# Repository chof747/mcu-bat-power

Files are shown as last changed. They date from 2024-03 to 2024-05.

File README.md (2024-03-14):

# mcu-bat-power

Battery power board for 5v compatible MCU boards featuring a LiFePo4 Holder

## Idea

This project is a battery supplied power circuitry to supply microcontroller projects with 5V battery power + the ability to charge and protect a LiFePo4 battery. In addition breakout for the USB data lines, voltage and current 
measurement as well as the sensing pins of the charging circuit are added so that a proper power management from
the microcontroller on an attached board is possible.

The concept of the board is to act as an add on board for a microcontroller board in a way that it can work for
several battery powered projects.

The idea is based on a Great Scott's video and materials of a [DIY LiPo Charge/Protect/5V Boost Circuit](https://www.youtube.com/watch?v=Fj0XuYiE7HU&t=618s)

## Components
This board includes a:

- LiFePo4 charging IC (CN3058E)
- Battery protection circuitry (HY2112 + FS8205)
- 5V Boost converter (MT3608 + passive components)
- A Micro USB socket to charge it conviniently from micro USB
- A power measurement circuit (INA219AxD with a 100mOhm sensing resistor)
- Leds for Power, Charging and Done
- A Power Switch
- Three connectors for other boards:
    - 5V/GND
    - Signals and Measuring:
        - Chargin and Done signal from the charging IC
        - I2C Bus for INA219A
        - VREF and GND connections to bring in the voltage level and power from a specific microcontroller
    - D+/D- from the USB Line

## Schematic & Board Layout

Schematic

Board Layout

## Revision History:

- **v1.0**: Initial version (Produced: 13.03.2024)<br/>
  This initial version includes a view additional features to enable better testing:
    - Test pads for all important voltage levels, signals and gnd
    - Additional pads to pass 5V power from a power supply
    - a bit more space (battery and circiutry are on the same side of the board)

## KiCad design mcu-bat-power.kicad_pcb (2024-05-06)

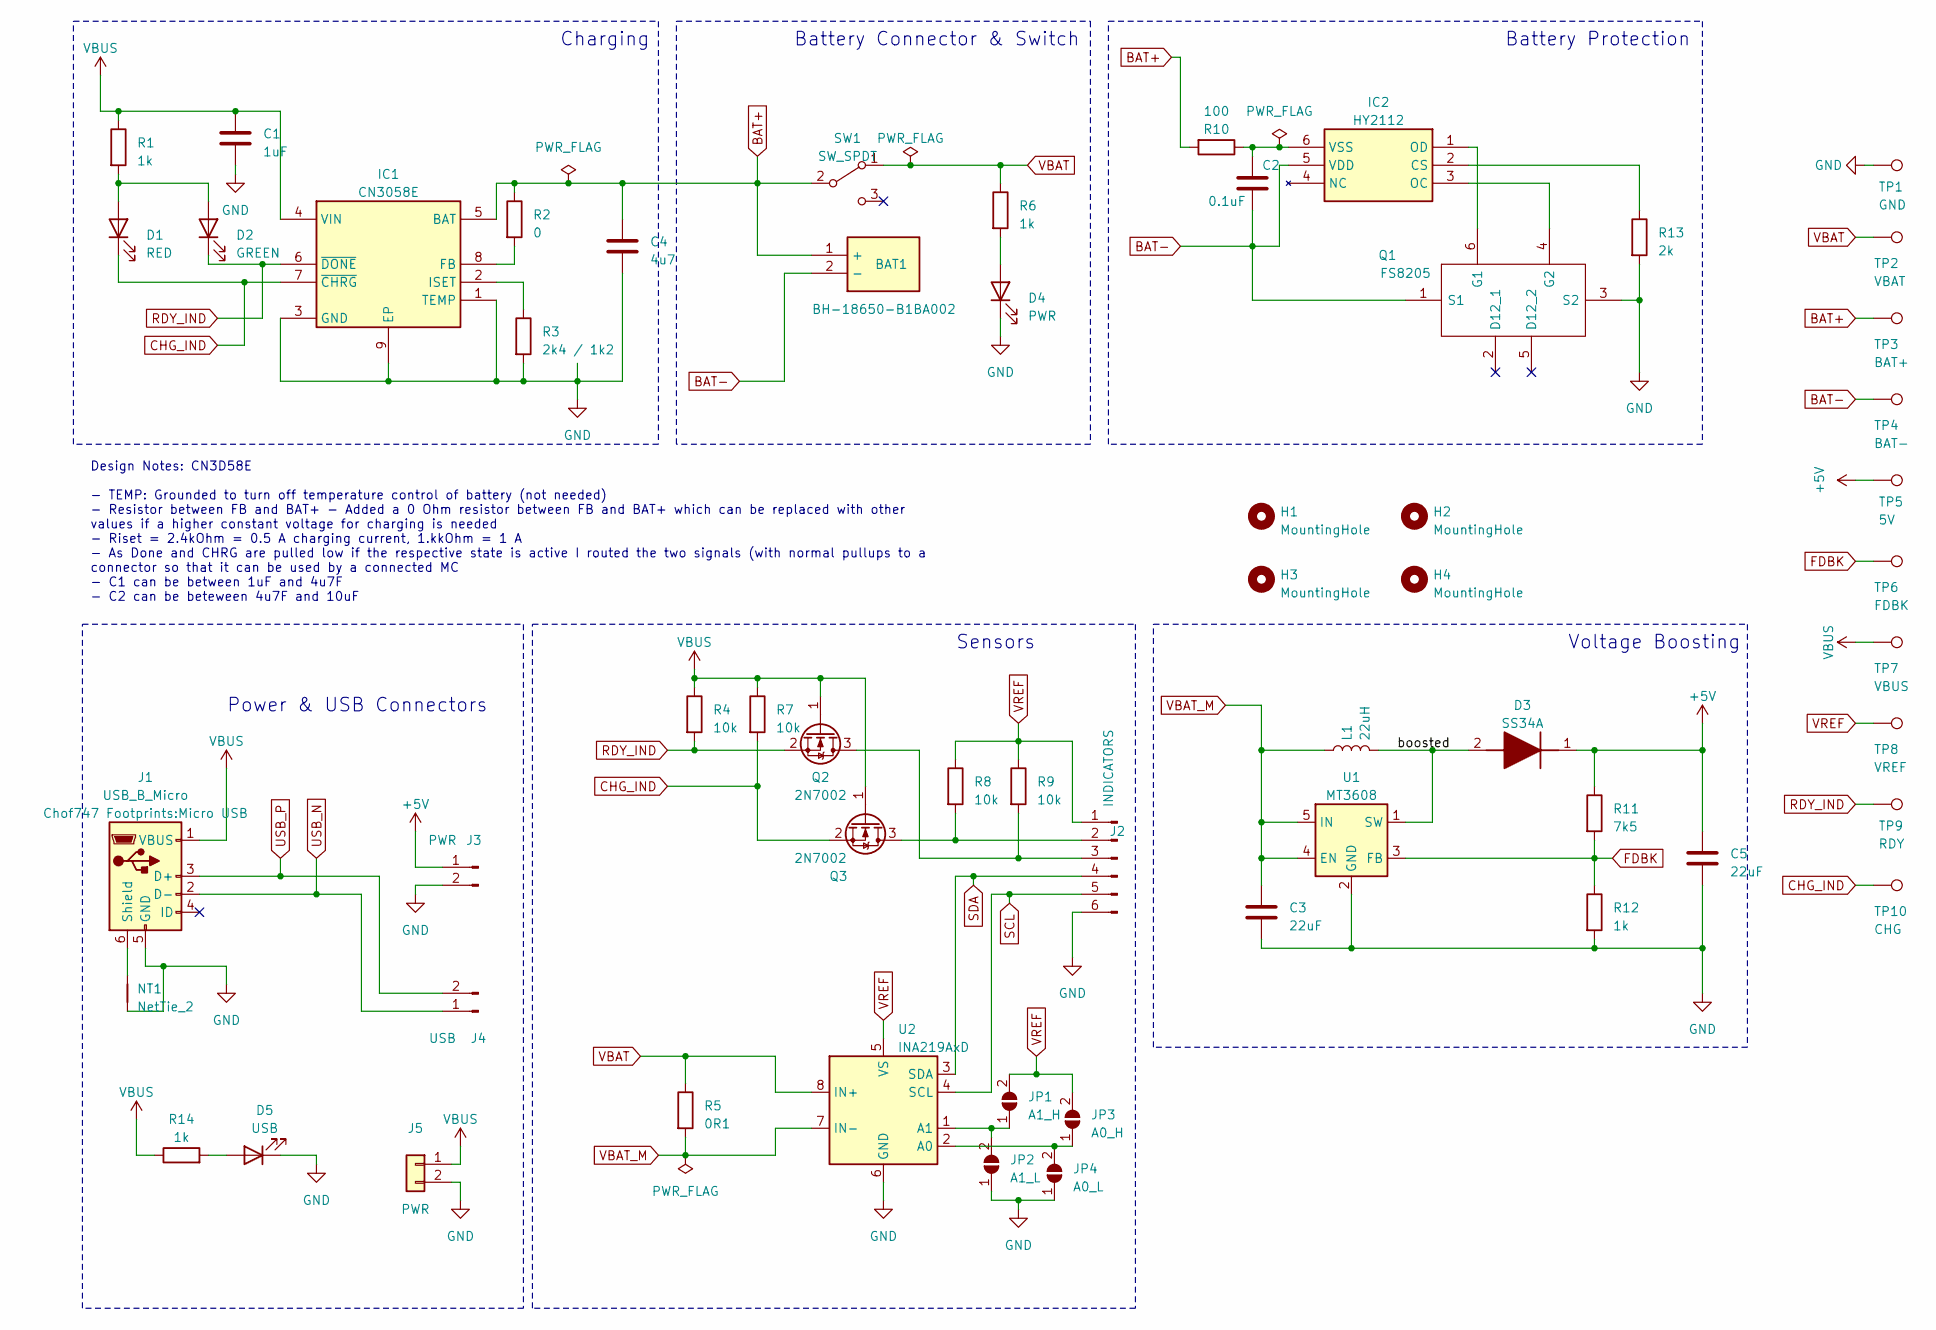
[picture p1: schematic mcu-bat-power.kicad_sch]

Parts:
BAT1: BH-18650-B1BA002; BH18650B1BA002; Manufacturer_Part_Number BH-18650-B1BA002
C1: 1uF; C_0603_1608Metric_Pad1.08x0.95mm_HandSolder
C2: 0.1uF; C_0603_1608Metric_Pad1.08x0.95mm_HandSolder
C3, C5: 22uF; C_1206_3216Metric_Pad1.33x1.80mm_HandSolder
C4: 4u7; C_0603_1608Metric_Pad1.08x0.95mm_HandSolder
D1: RED; LED_0603_1608Metric_Pad1.05x0.95mm_HandSolder
D2: GREEN; LED_0603_1608Metric_Pad1.05x0.95mm_HandSolder
D3: SS34A; DIOM5026X262N; Manufacturer_Part_Number SS34A
D4: PWR; LED_0603_1608Metric_Pad1.05x0.95mm_HandSolder
D5: USB; LED_0603_1608Metric_Pad1.05x0.95mm_HandSolder
H1, H2, H3, H4: MountingHole; MountingHole_3.2mm_M3-smallBorder
IC1: CN3058E; SOIC127P600X175-9N; Manufacturer_Part_Number CN3058E
IC2: HY2112; SOT95P280X145-6N; Manufacturer_Part_Number HY2112
J1: USB_B_Micro; Micro USB
J2: INDICATORS; PinHeader_1x06_P2.54mm_Horizontal
J3: PWR; PinHeader_1x02_P2.54mm_Horizontal
J4: USB; PinHeader_1x02_P2.54mm_Horizontal
J5: PWR; pad_1x2_1.5mmx3mm
JP1: A1_H; SolderJumper-2_P1.3mm_Open_RoundedPad1.0x1.5mm
JP2: A1_L; SolderJumper-2_P1.3mm_Open_RoundedPad1.0x1.5mm
JP3: A0_H; SolderJumper-2_P1.3mm_Open_RoundedPad1.0x1.5mm
JP4: A0_L; SolderJumper-2_P1.3mm_Open_RoundedPad1.0x1.5mm
L1: 22uH; SMD0740
NT1: NetTie_2; NetTie-2_SMD_Pad0.5mm
Q1: FS8205; Manufacturer_Part_Number FS8205
Q2, Q3: 2N7002; SOT-23
R1, R6, R12, R14: 1k; R_0603_1608Metric_Pad0.98x0.95mm_HandSolder
R2: 0; R_0603_1608Metric_Pad0.98x0.95mm_HandSolder
R3: 2k4 / 1k2; R_0603_1608Metric_Pad0.98x0.95mm_HandSolder
R4, R7, R8, R9: 10k; R_0603_1608Metric_Pad0.98x0.95mm_HandSolder
R5: 0R1; R_2512_6332Metric_Pad1.40x3.35mm_HandSolder
R10: 100; R_0603_1608Metric_Pad0.98x0.95mm_HandSolder
R11: 7k5; R_0603_1608Metric_Pad0.98x0.95mm_HandSolder
R13: 2k; R_0603_1608Metric_Pad0.98x0.95mm_HandSolder
SW1: SW_SPDT; Slide-switch-SS-12D11L7
TP1: GND; TestPoint_Pad_2.0x2.0mm
TP2: VBAT; TestPoint_Pad_2.0x2.0mm
TP3: BAT+; TestPoint_Pad_2.0x2.0mm
TP4: BAT-; TestPoint_Pad_2.0x2.0mm
TP5: 5V; TestPoint_Pad_2.0x2.0mm
TP6: FDBK; TestPoint_Pad_2.0x2.0mm
TP7: VBUS; TestPoint_Pad_2.0x2.0mm
TP8: VREF; TestPoint_Pad_2.0x2.0mm
TP9: RDY; TestPoint_Pad_2.0x2.0mm
TP10: CHG; TestPoint_Pad_2.0x2.0mm
U1: MT3608; SOT-23-6
U2: INA219AxD; SOIC-8_3.9x4.9mm_P1.27mm

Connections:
+5V: C5.1, D3.1 (K), J3.1, R11.1, TP5.1
/boosted: D3.2 (A), L1.2, U1.1 (SW)
BAT+: BAT1.1 (+), C4.1, IC1.5 (BAT), R2.1, R10.2, SW1.2 (B), TP3.1
BAT-: BAT1.2 (-), C2.2, IC2.5 (VDD), Q1.1 (S1), TP4.1
CHG_IND: D1.1 (K), IC1.7 (~CHRG), Q3.2 (S), R7.2, TP10.1
FDBK: R11.2, R12.1, TP6.1, U1.3 (FB)
GND: C1.2, C3.2, C4.2, C5.2, D4.1 (K), D5.1 (K), IC1.1 (TEMP), IC1.3 (GND), IC1.9 (EP), J1.5 (GND), J2.6, J3.2, J5.2, JP2.1 (A), JP4.1 (A), NT1.1, Q1.3 (S2), R3.2, R12.2, R13.2, TP1.1, U1.2 (GND), U2.6 (GND)
unnamed: D1.2 (A), D2.2 (A), R1.2
unnamed: D4.2 (A), R6.2
unnamed: D5.2 (A), R14.2
unnamed: IC1.8 (FB), R2.2
unnamed: IC1.2 (ISET), R3.1
unnamed: IC2.2 (CS), R13.1
unnamed: IC2.3 (OC), Q1.4 (G2)
unnamed: IC2.1 (OD), Q1.6 (G1)
unnamed: C2.1, IC2.6 (VSS), R10.1
unnamed: J1.6 (Shield), NT1.2
unnamed: J2.2, Q3.3 (D), R8.2
unnamed: J2.3, Q2.3 (D), R9.2
unnamed: JP1.1 (A), JP2.2 (B), U2.1 (A1)
unnamed: JP3.1 (A), JP4.2 (B), U2.2 (A0)
RDY_IND: D2.1 (K), IC1.6 (~DONE), Q2.2 (S), R4.2, TP9.1
SCL: J2.5, U2.4 (SCL)
SDA: J2.4, U2.3 (SDA)
USB_N: J1.2 (D-), J4.1
USB_P: J1.3 (D+), J4.2
VBAT: R5.1, R6.1, SW1.1 (A), TP2.1, U2.8 (IN+)
VBAT_M: C3.1, L1.1, R5.2, U1.4 (EN), U1.5 (IN), U2.7 (IN-)
VBUS: C1.1, IC1.4 (VIN), J1.1 (VBUS), J5.1, Q2.1 (G), Q3.1 (G), R1.1, R4.1, R7.1, R14.1, TP7.1
VREF: J2.1, JP1.2 (B), JP3.2 (B), R8.1, R9.1, TP8.1, U2.5 (VS)

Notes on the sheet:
Design Notes: CN3D58E - TEMP: Grounded to turn off temperature control of battery (not needed) - Resistor between FB and BAT+ - Added a 0 Ohm resistor between FB and BAT+ which can be replaced with other values if a higher constant voltage for charging is needed - Riset = 2.4kOhm = 0.5 A charging c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
Battery Connector & Switch
Charging
Voltage Boosting
Sensors
Power & USB Connectors
Battery Protection

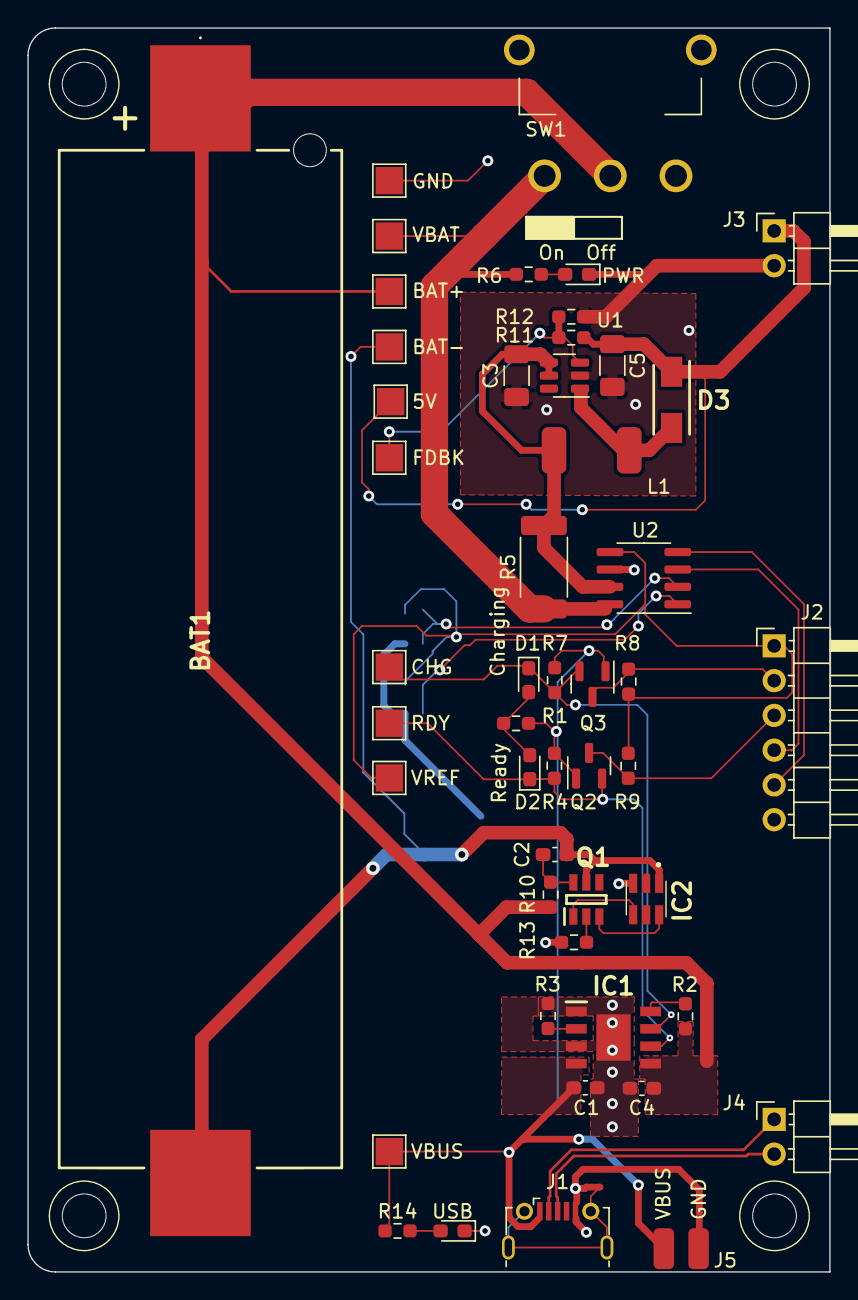
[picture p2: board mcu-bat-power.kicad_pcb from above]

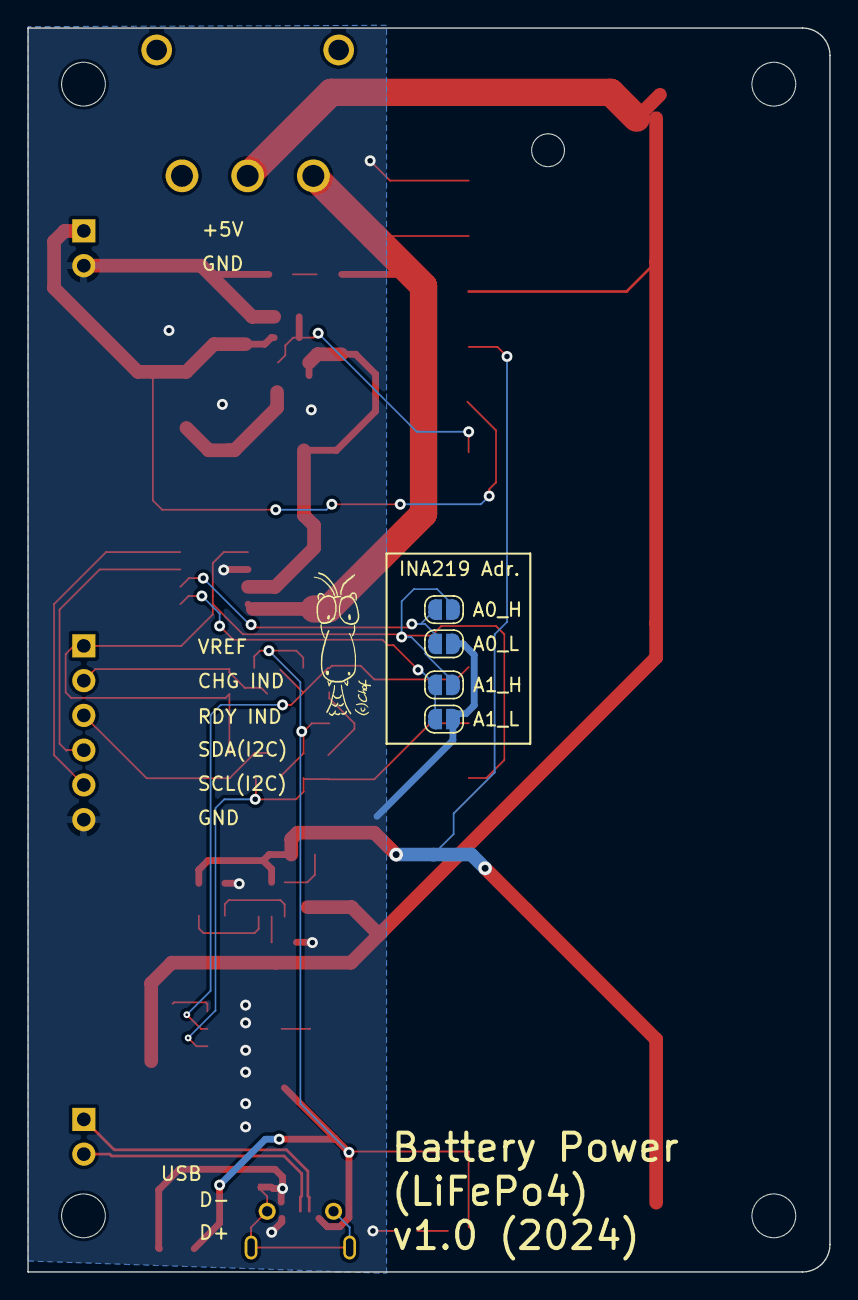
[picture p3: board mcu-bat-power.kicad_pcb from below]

Board: 2 copper layers, 58.6 x 90.9 mm, 58 parts (4 on the bottom side), 30 nets.

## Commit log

2023-10-11 renaming and initialization
    [mcu-bat-power.kicad_pcb, mcu-bat-power.kicad_sch]
2023-10-26 First version with all components set and placed
    [mcu-bat-power.kicad_pcb, mcu-bat-power.kicad_sch]
2023-11-05 running dcr checks and excluding unnecessary issues
    [mcu-bat-power.kicad_pcb]
2024-03-14 Version 1.0 (sent to fabhouse) + updated readme
    [mcu-bat-power.kicad_pcb, mcu-bat-power.kicad_sch]
2024-03-14 upgrade to KiCad 8.0
2024-05-06 Changes due to KiCad8 + setting origin
    [mcu-bat-power.kicad_pcb, mcu-bat-power.kicad_sch]
